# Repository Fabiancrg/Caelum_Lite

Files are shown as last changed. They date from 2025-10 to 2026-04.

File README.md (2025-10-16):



| Supported Targets | ESP32-C6 | ESP32-H2 || Supported Targets | ESP32-C6 | ESP32-H2 |

| ----------------- |  -------- | -------- || ----------------- |  -------- | -------- |

# ESP32 Zigbee Weather Station# ESP32 Zigbee Multi-Sensor Device

This project implements a comprehensive weather monitoring station using ESP32-C6 with Zigbee connectivity. The device is derived from the ZigbeeMultiSensor project and provides real-time environmental monitoring with multiple sensors.This project implements a comprehensive environmental monitoring device using ESP32-C6 with Zigbee connectivity. The device combines multiple sensors and actuators into a single Zigbee end-device with five distinct endpoints.

This project is based on the examples provided in the ESP Zigbee SDK:This project is based on the exmaples provided in the ESP Zigbee SDK :

* [ESP Zigbee SDK Docs](https://docs.espressif.com/projects/esp-zigbee-sdk)* [ESP Zigbee SDK Docs](https://docs.espressif.com/projects/esp-zigbee-sdk)

* [ESP Zigbee SDK Repo](https://github.com/espressif/esp-zigbee-sdk)* [ESP Zigbee SDK Repo](https://github.com/espressif/esp-zigbee-sdk)

## Device Features## Device Features

### 🌐 Zigbee Endpoints Overview### 🌐 Zigbee Endpoints Overview

| Endpoint | Device Type | Clusters | Description || Endpoint | Device Type | Clusters | Description |

|----------|-------------|----------|-------------||----------|-------------|----------|-------------|

| **1** | LED Strip Light | On/Off | Addressable LED strip (GPIO 8) with status indication || **1** | LED Strip Light | On/Off | Addressable LED strip (GPIO 8) with full on/off control |

| **2** | GPIO LED Light | On/Off | Single GPIO LED (GPIO 0) for secondary status || **2** | GPIO LED Light | On/Off | Single GPIO LED (GPIO 0) for secondary lighting |

| **3** | Button Sensor | Analog Input | External button (GPIO 12) with multi-action detection || **3** | Button Sensor | Analog Input | External button (GPIO 12) with multi-action detection |

| **4** | Environmental Sensor | Temperature, Humidity, Pressure | BME280 sensor via I2C (GPIO 6/7) || **4** | Environmental Sensor | Temperature, Humidity, Pressure | BME280 sensor via I2C (GPIO 6/7) |

| **5** | Rain Gauge | Analog Input | Tipping bucket rain sensor (GPIO 18) with rainfall totals || **5** | Rain Gauge | Analog Input | Tipping bucket rain sensor (GPIO 18) with rainfall totals |

### 📋 Weather Monitoring Capabilities### 📋 Detailed Endpoint Descriptions

#### **Temperature Monitoring** 🌡️#### **Endpoint 1: LED Strip Controller** 

- Range: -40°C to +85°C- **Hardware**: WS2812B-compatible LED strip on GPIO 8

- Accuracy: ±1°C- **Functionality**: Full on/off control with Zigbee integration

- Real-time updates via Zigbee reporting- **Features**: Hardware state tracking, button toggle support

- **Use Case**: Primary lighting control and status indication

#### **Humidity Monitoring** 💧

- Range: 0-100% RH#### **Endpoint 2: GPIO LED Controller**

- Accuracy: ±3% RH- **Hardware**: Standard LED on GPIO 0  

- Automatic dew point calculation- **Functionality**: Simple on/off switching

- **Features**: Independent control from LED strip

#### **Barometric Pressure** ☁️- **Use Case**: Secondary status indicator or backup lighting

- Range: 300-1100 hPa

- Weather trend prediction#### **Endpoint 3: Smart Button Interface**

- Altitude compensation- **Hardware**: Push button on GPIO 12

- **Functionality**: Multi-action detection (single, double, hold, release)

#### **Rainfall Measurement** 🌧️- **Features**: Debounced input, action encoding, press counting

- Tipping bucket sensor support- **Use Case**: User interface for device control and interaction

- Cumulative rainfall tracking

- Configurable reset intervals#### **Endpoint 4: Environmental Monitoring**

- **Hardware**: BME280 sensor via I2C (SDA: GPIO 6, SCL: GPIO 7)

### 🔧 Hardware Requirements- **Measurements**: 

  - 🌡️ **Temperature**: -40°C to +85°C (±1°C accuracy)

- **MCU**: ESP32-C6 or ESP32-H2  - 💧 **Humidity**: 0-100% RH (±3% accuracy) 

- **Environmental Sensor**: BME280 (I2C)  - 🌪️ **Pressure**: 300-1100 hPa (±1 hPa accuracy)

  - SDA: GPIO 6- **Features**: Automatic 30-second reporting, Zigbee-standard units

  - SCL: GPIO 7- **Use Case**: Weather monitoring, HVAC automation, air quality tracking

- **Rain Sensor**: Tipping bucket on GPIO 18

- **LED Strip**: WS2812B on GPIO 8 (optional)#### **Endpoint 5: Rain Gauge System**

- **Status LED**: GPIO 0 (optional)- **Hardware**: Tipping bucket rain gauge on GPIO 18

- **Button**: GPIO 12 (optional)- **Measurements**: Cumulative rainfall in millimeters (0.36mm per tip)

- **Features**: 

### 📊 Zigbee Integration  - Advanced debouncing (200ms + 1000ms bounce settle)

  - Persistent storage (NVS) for total tracking

- **Protocol**: Zigbee 3.0  - Smart reporting (1mm threshold OR hourly)

- **Device Type**: End Device (Router mode available)  - Network-aware operation (only active when connected)

- **Supported Channels**: 11-26 (2.4 GHz)- **Specifications**: 

- **Compatible**: Zigbee2MQTT, Home Assistant ZHA, Hubitat  - Maximum rate: 200mm/hour supported

  - Accuracy: ±0.36mm per bucket tip

### 🚀 Getting Started  - Storage: Non-volatile total persistence across reboots

- **Use Case**: Weather station, irrigation control, flood monitoring

#### Prerequisites

```bash### 🔧 Hardware Configuration

# Install ESP-IDF v5.5.1 or later

git clone -b v5.5.1 --recursive https://github.com/espressif/esp-idf.git#### **Required Components**

cd esp-idf- ESP32-C6 development board

./install.sh esp32c6- BME280 environmental sensor module

. ./export.sh- WS2812B LED strip (at least 1 LED)

```- Standard LED + resistor

- Push button + pull-up resistor  

#### Build and Flash- Tipping bucket rain gauge with reed switch

```bash- Zigbee coordinator (ESP32-H2 or commercial gateway)

cd WeatherStation

idf.py set-target esp32c6#### **Pin Assignments**

idf.py build```

idf.py -p COM_PORT flash monitorGPIO 0  - GPIO LED output

```GPIO 6  - I2C SDA (BME280)

GPIO 7  - I2C SCL (BME280) 

#### First BootGPIO 8  - LED strip data (WS2812B)

1. Device will create a Zigbee network or join existing oneGPIO 9  - Built-in button (factory reset)

2. LED indicators show connection statusGPIO 12 - External button input

3. Long-press button (5s) for factory resetGPIO 18 - Rain gauge input (reed switch)

```

### 📡 Data Reporting

## 🚀 Quick Start

- **Temperature/Humidity**: Every 30 seconds or on significant change

- **Pressure**: Every 60 seconds### Configure the Project

- **Rainfall**: Immediate on tip detection```bash

- **Button Events**: Immediate (single, double, hold, release)idf.py set-target esp32c6

idf.py menuconfig

### 🏠 Home Assistant Integration```

The device appears as a Zigbee climate sensor with:### Build and Flash

- Temperature sensor```bash

- Humidity sensor# Erase previous data (recommended for first flash)

- Pressure sensoridf.py -p [PORT] erase-flash

- Rainfall sensor

- LED controls# Build and flash the project

- Button entityidf.py -p [PORT] flash monitor

```

### 🛠️ Configuration

### Device Operation

Key parameters can be adjusted in `main/esp_zb_light.h`:

- Reporting intervals#### **Button Controls**

- Sensor calibration offsets- **Built-in Button (GPIO 9)**:

- Rain tip bucket volume  - Short press: Toggle LED strip on/off

- LED behavior  - Long press (hold): Factory reset device

- **External Button (GPIO 12)**: 

### 📝 Project Structure  - Reports all actions (single, double, hold, release) to Zigbee

```#### **Automatic Features**

WeatherStation/- Environmental data reported every 30 seconds

├── main/- Rain gauge totals stored persistently  

│   ├── esp_zb_light.c       # Main Zigbee stack logic- Smart rainfall reporting (1mm increments or hourly)

│   ├── esp_zb_light.h       # Configuration and headers- Network connection status monitoring

│   ├── bme280_app.c         # BME280 sensor driver

│   ├── bme280_app.h         # BME280 interface## 📊 Example Output

│   ├── light_driver.c       # LED strip and GPIO control

│   └── light_driver.h       # Light driver interface### Device Initialization

├── CMakeLists.txt           # Build configuration```

├── sdkconfig.defaults       # Default SDK settingsI (403) app_start: Starting scheduler on CPU0

└── README.md                # This fileI (408) ESP_ZB_ON_OFF_LIGHT: Initialize Zigbee stack

```I (558) ESP_ZB_ON_OFF_LIGHT: Deferred driver initialization successful

I (568) ESP_ZB_ON_OFF_LIGHT: BME280 sensor initialized successfully

### 🔄 Based OnI (578) ESP_ZB_ON_OFF_LIGHT: Rain gauge initialized successfully. Current total: 0.00 mm

I (578) ESP_ZB_ON_OFF_LIGHT: Start network steering

This project is derived from the ESP32 Zigbee Multi-Sensor Device project and inherits its multi-endpoint architecture optimized for weather station applications.```

### 📄 License### Network Connection

```

This project follows the license terms of the ESP Zigbee SDK.I (3558) ESP_ZB_ON_OFF_LIGHT: Joined network successfully (Extended PAN ID: 74:4d:bd:ff:fe:63:f7:30, PAN ID: 0x13af, Channel:13, Short Address: 0x7c16)

I (3568) RAIN_GAUGE: Rain gauge enabled - device connected to Zigbee network

### 🤝 Contributing```

Contributions are welcome! Please feel free to submit issues or pull requests.### Sensor Data Reporting

```

### 💖 SupportI (30000) ESP_ZB_ON_OFF_LIGHT: 🌡️ Temperature: 22.35°C reported to Zigbee  

I (30010) ESP_ZB_ON_OFF_LIGHT: 💧 Humidity: 45.20% reported to Zigbee

If you find this project useful, consider supporting the development:I (30020) ESP_ZB_ON_OFF_LIGHT: 🌪️ Pressure: 1013.25 hPa reported to Zigbee

I (30030) ESP_ZB_ON_OFF_LIGHT: 📡 Temp: 22.4°C

[![ko-fi](https://ko-fi.com/img/githubbutton_sm.svg)](https://ko-fi.com/Fabiancrg)I (30040) ESP_ZB_ON_OFF_LIGHT: 📡 Humidity: 45.2%

I (30050) ESP_ZB_ON_OFF_LIGHT: 📡 Pressure: 1013.3 hPa
```

### Button Interactions  
```
I (45000) ESP_ZB_ON_OFF_LIGHT: 🔘 External button action detected: single
I (45010) ESP_ZB_ON_OFF_LIGHT: ✅ Button action single sent (encoded: 1001.0) - press #1
I (45020) ESP_ZB_ON_OFF_LIGHT: 📡 Button: single (#1)
```

### Rain Gauge Activity
```  
I (60000) RAIN_GAUGE: 🔍 Rain gauge interrupt received on GPIO18 (enabled: YES)
I (60010) RAIN_GAUGE: 🌧️ Rain pulse #1 detected! Total: 0.36 mm (+0.36 mm)
I (60020) RAIN_GAUGE: ✅ Rainfall total 0.36 mm reported to Zigbee
I (60030) ESP_ZB_ON_OFF_LIGHT: 📡 Rain: 0.36 mm
```

## 🏠 Home Assistant Integration

When connected to Zigbee2MQTT or other Zigbee coordinators, the device appears as:

- **2x Switch entities**: LED Strip & GPIO LED control
- **1x Sensor entity**: Button actions with press counter
- **3x Sensor entities**: Temperature, Humidity, Pressure  
- **1x Sensor entity**: Rainfall total with automatic updates

### Device Information
- **Manufacturer**: ESPRESSIF
- **Model**: esp32c6  
- **Firmware**: v5.5.1
- **Supported**: Automatic device detection in Zigbee2MQTT

## 🔧 Troubleshooting

### Common Issues

#### **Rain Gauge Not Detecting**
- Verify GPIO 18 connections and reed switch operation
- Check that device is connected to Zigbee network (rain gauge only active when connected)
- Ensure proper pull-down resistor on rain gauge input

#### **BME280 Not Reading**  
- Check I2C connections (SDA: GPIO 6, SCL: GPIO 7)
- Verify BME280 I2C address (default: 0x76 or 0x77)
- Ensure proper power supply to sensor (3.3V)

#### **Button Not Responding**
- Verify button connections and pull-up resistors
- Check GPIO 12 (external) and GPIO 9 (built-in) functionality
- Ensure proper debouncing in hardware

#### **Zigbee Connection Issues**
- Perform factory reset with long press on built-in button
- Ensure Zigbee coordinator is in pairing mode
- Check channel compatibility between coordinator and device

### 📋 Development Notes

- **ESP-IDF Version**: v5.5.1 recommended
- **Zigbee SDK**: Latest ESP Zigbee SDK required  
- **Memory Usage**: ~2MB flash, ~200KB RAM typical
- **Power Consumption**: ~100mA active, supports deep sleep for battery operation

### 🆘 Support

For technical queries, please open an [issue](https://github.com/espressif/esp-idf/issues) on GitHub. Include:
- Complete serial monitor output
- Hardware configuration details  
- ESP-IDF and SDK versions
- Specific symptoms and reproduction steps

---

**Project**: ESP32 Zigbee Multi-Sensor Device  
**Version**: v1.0  
**Compatible**: ESP32-C6, ESP-IDF v5.5.1+  
**License**: Apache 2.0

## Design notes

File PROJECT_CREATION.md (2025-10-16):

# WeatherStation Project Creation Summary

## Overview
Successfully created a new **WeatherStation** project based on the **ZigbeeMultiSensor** project.

## Project Location
```
c:\Devel\Repositories\WeatherStation
```

## What Was Done

### 1. Project Structure Copied
All essential files and directories were copied from ZigbeeMultiSensor:
- ✅ Source code (`main/` directory with all .c and .h files)
- ✅ Build configuration (`CMakeLists.txt`, `sdkconfig`, `sdkconfig.defaults`)
- ✅ Development tools (`.vscode/`, `.devcontainer/`, `.clangd`)
- ✅ Project metadata (`.gitignore`, `partitions.csv`)

### 2. Excluded Items (Clean Copy)
The following were intentionally excluded:
- ❌ `.git/` - No git history (fresh start)
- ❌ `build/` - Build artifacts (will be regenerated)
- ❌ `managed_components/` - Will be downloaded on first build
- ❌ `dependencies.lock` - Will be regenerated
- ❌ Build logs and temporary files

### 3. Project Renamed
- **CMakeLists.txt**: Project name changed from `zigbeeTest` to `WeatherStation`
- **README.md**: Completely rewritten for weather station focus

## Project Features (Inherited from ZigbeeMultiSensor)

### Hardware Support
- **MCU**: ESP32-C6 or ESP32-H2
- **Zigbee**: Full Zigbee 3.0 stack with 5 endpoints

### Endpoints Configuration
1. **Endpoint 1**: LED Strip (WS2812B on GPIO 8)
2. **Endpoint 2**: GPIO LED (GPIO 0)
3. **Endpoint 3**: Button Sensor (GPIO 12)
4. **Endpoint 4**: BME280 Environmental Sensor (I2C on GPIO 6/7)
5. **Endpoint 5**: Rain Gauge (GPIO 18)

### Source Files Included
```
main/
├── bme280_app.c         # BME280 sensor driver
├── bme280_app.h         # BME280 interface
├── esp_zb_light.c       # Main Zigbee stack (49KB)
├── esp_zb_light.h       # Configuration headers
├── light_driver.c       # LED/GPIO control (19KB)
├── light_driver.h       # Driver interface
├── CMakeLists.txt       # Component config
└── idf_component.yml    # Dependencies
```

## Next Steps

### 1. Initialize Git (Optional)
```bash
cd c:\Devel\Repositories\WeatherStation
git init
git add .
git commit -m "Initial commit - Weather Station project based on ZigbeeMultiSensor"
```

### 2. Build the Project
```bash
cd c:\Devel\Repositories\WeatherStation

# Set target (if not already set)
idf.py set-target esp32c6

# Build
idf.py build
```

### 3. Flash to Device
```bash
# Erase flash (recommended for first flash)
idf.py erase-flash

# Flash and monitor
idf.py -p COM_PORT flash monitor
```

### 4. Customization Ideas
Consider modifying for weather station specific features:
- Add weather trend calculation (pressure changes)
- Implement data logging to flash
- Add wind speed/direction sensors
- Customize LED patterns for weather alerts
- Add battery monitoring for solar power

## Configuration Files

### Key Settings in `sdkconfig`
- Zigbee role: End Device (can be changed to Router)
- I2C configuration for BME280
- GPIO assignments for sensors and LEDs

### Component Dependencies (`main/idf_component.yml`)
- LED strip driver
- BME280 sensor library
- ESP-Zigbee libraries

## Differences from Original

| Aspect | ZigbeeMultiSensor | WeatherStation |
|---|---|---|
| Project Name | `zigbeeTest` | `WeatherStation` |
| README | Multi-sensor focus | Weather station focus |
| Git History | Preserved | Fresh start (no .git) |
| Build Artifacts | May exist | Clean (excluded) |

## Testing Checklist

Before first use, verify:
- [ ] ESP-IDF environment is set up (v5.5.1+)
- [ ] ESP32-C6 or ESP32-H2 hardware available
- [ ] BME280 sensor connected to I2C (GPIO 6/7)
- [ ] USB cable and COM port identified
- [ ] Zigbee coordinator running (Zigbee2MQTT or ZHA)

## Support

This project inherits all features from ZigbeeMultiSensor and is optimized for weather monitoring applications.

For issues or contributions, refer to the main README.md in the project directory.

---
**Created**: October 16, 2025
**Based on**: ZigbeeMultiSensor by Fabiancrg
**Status**: Ready to build and flash

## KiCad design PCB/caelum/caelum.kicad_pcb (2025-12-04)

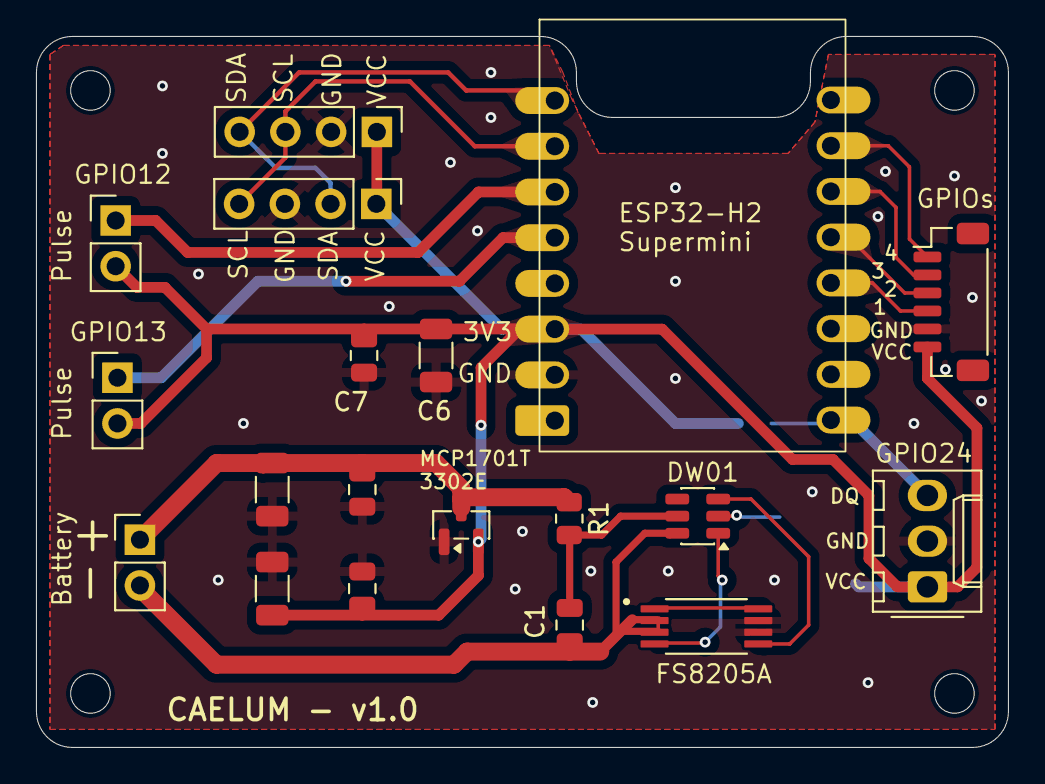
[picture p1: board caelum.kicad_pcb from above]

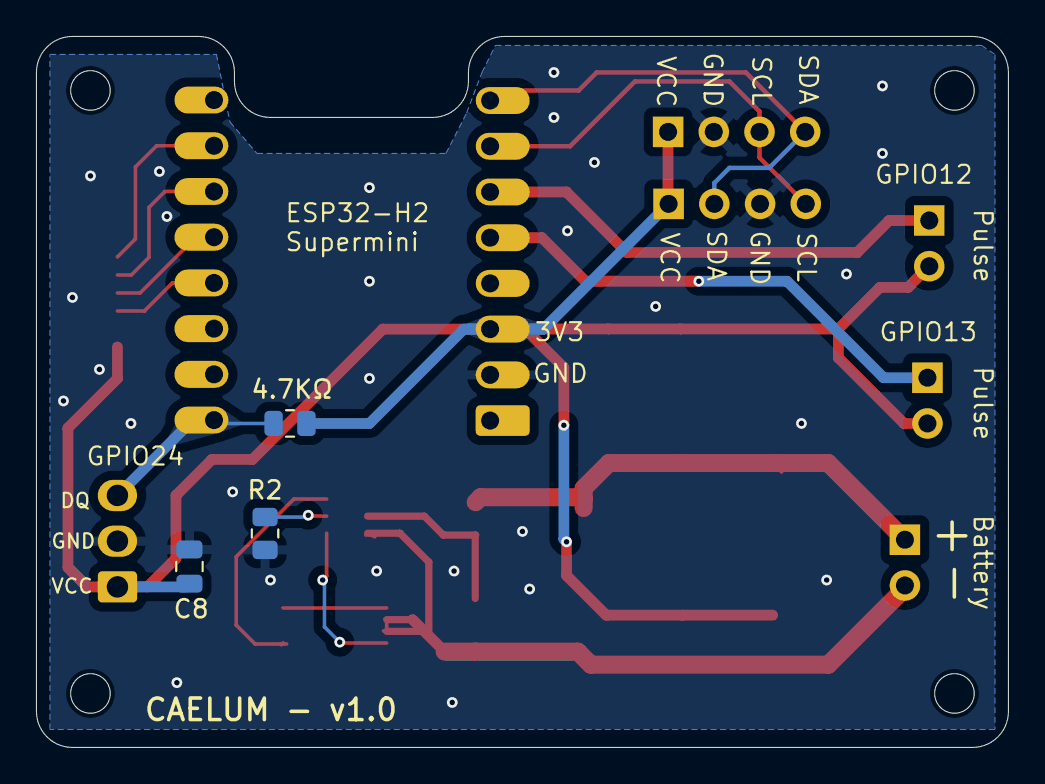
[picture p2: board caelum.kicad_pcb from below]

Board: 2 copper layers, 54.0 x 39.5 mm, 26 parts (3 on the bottom side), 18 nets.

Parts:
C1, C3, C5, C7, C8: 0.1µF; C_0805_2012Metric
C2, C4, C6: 1µF; C_1206_3216Metric
H1, H2, H3, H4: MountingHole; MountingHole_2.2mm_M2
J1: Conn_01x06_Pin; JST_SH_BM06B-SRSS-TB_1x06-1MP_P1.00mm_Vertical
J3: Pulse1; PinHeader_1x02_P2.54mm_Vertical
J4: Batt; PinHeader_1x02_P2.54mm_Vertical
J6: Pulse2; PinHeader_1x02_P2.54mm_Vertical
J7, J10: Conn_01x04_Pin; PinHeader_1x04_P2.54mm_Vertical
J8: DS18B20; Molex_KK-254_AE-6410-03A_1x03_P2.54mm_Vertical
Q1: FS8205A-FC; SOP65P640X120-8N-FC
R1: 100R; R_0805_2012Metric
R2: 1K; R_0805_2012Metric
R3: 4.7K; R_0805_2012Metric
U1: DW01A; SOT-23-6
U2: MCP1700T-3302E; SOT-23
U3: ESP32-H2-SUPERMINI; ESP32H2-Supermini

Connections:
+3V3: C4.2, C5.2, C6.1, C7.1, C8.2, J1.6, J3.2, J6.2, J7.1, J8.1, J10.1, R3.1, U2.2 (VO), U3.7 (3V3)
BATT+: C2.1, C3.1, J4.1, R1.1, U2.3 (VI)
BATT-: C1.2, J4.2, Q1.2 (S1), Q1.3 (S1), U1.6 (GND)
GPIO1: J1.4, U3.16 (IO1)
GPIO2: J1.3, U3.15 (IO2)
GPIO3: J1.2, U3.14 (IO3)
GPIO4: J1.1, U3.13 (IO4)
GPIO12: J3.1, U3.4 (IO12)
GPIO13: J6.1, U3.5 (IO13)
GPIO24: J8.3, R3.2, U3.19 (IO24)
unnamed: Q1.1 (D12), Q1.8 (D12)
unnamed: Q1.4 (G1), U1.1 (OD)
unnamed: Q1.5 (G2), U1.3 (OC)
unnamed: R2.1, U1.2 (CS)
unnamed: C1.1, R1.2, U1.5 (VCC)
OUT-: C2.2, C3.2, C4.1, C5.1, C6.2, C7.2, C8.1, J1.5, J7.3, J8.2, J10.2, Q1.6 (S2), Q1.7 (S2), R2.2, U2.1 (GND), U3.8 (GND)
SCL: J7.4, J10.3, U3.3 (IO11)
SDA: J7.2, J10.4, U3.2 (IO10)

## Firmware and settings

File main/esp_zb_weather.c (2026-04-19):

/*
 * SPDX-FileCopyrightText: 2021-2024 Espressif Systems (Shanghai) CO LTD
 *
 * SPDX-License-Identifier:  LicenseRef-Included
 *
 * ESP32-H2 Zigbee Weather Station with Light Sleep
 *
 * Battery-powered weather station with 5-minute periodic sensor readings.
 * Rain gauge triggers immediate attribute updates on each pulse.
 * Uses light sleep to maintain Zigbee network connection.
 * All reporting controlled by Zigbee coordinator configuration.
 */
#include "freertos/FreeRTOS.h"
#include "freertos/task.h"
#include "freertos/queue.h"
#include "freertos/semphr.h"
#include "esp_check.h"
#include "esp_log.h"
#include "nvs_flash.h"
#include "ha/esp_zigbee_ha_standard.h"
#include "esp_zb_weather.h"
#include "esp_zb_ota.h"
#include "sleep_manager.h"
#include "driver/gpio.h"
#include "bme280_app.h"
#include "sensor_if.h"
#include "i2c_bus.h"
#include "nvs.h"
#include "weather_driver.h"
#include "esp_adc/adc_oneshot.h"
#include "esp_adc/adc_cali.h"
#include "esp_adc/adc_cali_scheme.h"
#include "esp_ota_ops.h"
#include "esp_app_format.h"
#include "esp_timer.h"
#include "esp_pm.h"
#include "esp_sleep.h"
#include "esp_rom_uart.h"
#include "driver/rmt_tx.h"
#include "driver/rmt_rx.h"
/* Generated header with FW_VERSION / FW_DATE_CODE - created at configure time */
#include "version.h"

/* OTA upgrade running versions */
#ifndef OTA_UPGRADE_RUNNING_FILE_VERSION
#define OTA_UPGRADE_RUNNING_FILE_VERSION                      0x00000000U
#endif
#ifndef OTA_UPGRADE_RUNNING_STACK_VERSION
#define OTA_UPGRADE_RUNNING_STACK_VERSION                     0x0002U
#endif

#if !defined ZB_ED_ROLE
#error Define ZB_ED_ROLE in idf.py menuconfig to compile Weather Station (End Device) source code.
#endif

/* Zigbee Sleepy End Device (SED) configuration */
#define ZIGBEE_KEEP_ALIVE_MS        7500    // Keep-alive poll interval (7.5 seconds)
#define ZIGBEE_SLEEP_THRESHOLD_MS   6000    // Idle time before sleep signal (6 seconds)
#define ZIGBEE_ED_TIMEOUT           ESP_ZB_ED_AGING_TIMEOUT_64MIN  // Parent timeout

/* Power optimization notes:
 * - Sleep threshold MUST be < keep_alive to allow CAN_SLEEP signal before next poll
 * - Lower threshold = faster sleep entry = better battery life
 * - Higher threshold = more time for multiple reports = fewer wake cycles
 * - Current setting (6s): Optimal for 15-min reporting with occasional rain events
 * - Measured performance: 0.68mA sleep, 12mA transmit, ~0.83mA average
 * - Battery life: ~125 days (4 months) on 2500mAh Li-Ion
 */

static const char *TAG = "WEATHER_STATION";
//static const char *RAIN_TAG = "RAIN_GAUGE";

/* Network connection status - declared early for LED functions */
static bool zigbee_network_connected = false;

/* Sleep prevention during initial configuration
 * Prevents device from sleeping for 60 seconds after joining network
 * This gives coordinator (Z2M) time to configure reporting without interruption.
 * IMPORTANT: We use a PM lock instead of skipping esp_zb_sleep_now() — the Zigbee
 * stack requires that esp_zb_sleep_now() is ALWAYS called on CAN_SLEEP, otherwise
 * the internal critical section nesting becomes unbalanced and causes a crash. */
static int64_t network_join_time_us = 0;
static esp_pm_lock_handle_t config_pm_lock = NULL;
#define INITIAL_CONFIG_DELAY_SEC 60  // Wait 60 seconds before allowing sleep after join

/* LED is used only during boot/join process:
 * - Blink yellow/orange during network joining
 * - Steady blue when successfully connected
 * - Blink red after max connection retries failed
 * After successful join, LED strip is deinitialized to save power */

#include "led_strip.h"

/* Debug LED variables for RGB LED */
static led_strip_handle_t led_strip = NULL;
static bool led_blink_task_running = false;
static TaskHandle_t led_blink_task_handle = NULL;

/* LED control functions for WS2812 RGB LED */
static void debug_led_init(void)
{
    /* LED strip configuration for WS2812 (older API for led_strip ~2.0.0) */
    led_strip_config_t strip_config = {
        .strip_gpio_num = DEBUG_LED_GPIO,
        .max_leds = 1,                         // Only 1 LED
    };
    
    /* LED strip RMT configuration (older API) */
    led_strip_rmt_config_t rmt_config = {
        .resolution_hz = 10 * 1000 * 1000,     // 10MHz
    };
    
    ESP_ERROR_CHECK(led_strip_new_rmt_device(&strip_config, &rmt_config, &led_strip));
    
    /* Turn off LED initially */
    led_strip_clear(led_strip);
    ESP_LOGI(TAG, "Debug RGB LED initialized on GPIO%d (WS2812)", DEBUG_LED_GPIO);
}

static void debug_led_deinit(void)
{
    /* Deinitialize LED strip to power down RMT peripheral
     * Called after successful network join to save power */
    if (led_strip) {
        led_strip_clear(led_strip);  // Clear pixels first
        led_strip_del(led_strip);    // Delete LED strip handle (powers down RMT)
        led_strip = NULL;
        ESP_LOGI(TAG, "🔌 RGB LED RMT peripheral powered down (boot sequence complete)");
    }
}

/* Properly-typed wrapper for esp_zb_scheduler_alarm (avoids UB from void(void)->void(uint8_t) cast) */
static void debug_led_deinit_cb(uint8_t param)
{
    (void)param;
    debug_led_deinit();
}

static void debug_led_set_blue(void)
{
    /* Set steady blue for successful connection */
    if (led_strip) {
        led_strip_set_pixel(led_strip, 0, 0, 0, 16);  // R=0, G=0, B=16 (dim blue)
        led_strip_refresh(led_strip);
    }
}

static void debug_led_blink_task(void *arg)
{
    while (led_blink_task_running) {
        if (!led_strip) break;  // Stop if LED was deinitialized
        
        /* Yellow/orange blink for network joining */
        led_strip_set_pixel(led_strip, 0, 16, 8, 0);  // R=16, G=8, B=0 (dim yellow/orange)
        led_strip_refresh(led_strip);
        vTaskDelay(pdMS_TO_TICKS(500));  // ON for 500ms
        
        led_strip_set_pixel(led_strip, 0, 0, 0, 0);   // OFF
        led_strip_refresh(led_strip);
        vTaskDelay(pdMS_TO_TICKS(500));  // OFF for 500ms
    }
    vTaskDelete(NULL);
}

static void debug_led_start_blink(void)
{
    if (!led_strip) return;  // LED already deinitialized
    
    if (!led_blink_task_running) {
        led_blink_task_running = true;
        xTaskCreate(debug_led_blink_task, "led_blink", 2048, NULL, 5, &led_blink_task_handle);
        ESP_LOGI(TAG, "RGB LED blink started (network joining)");
    }
}

static void debug_led_stop_blink(void)
{
    if (led_blink_task_running) {
        led_blink_task_running = false;
        if (led_blink_task_handle) {
            vTaskDelay(pdMS_TO_TICKS(10));  // Give task time to exit
            led_blink_task_handle = NULL;
        }
    }
}

static void debug_led_blink_red(void)
{
    /* Blink red to indicate connection failure after max retries */
    if (!led_strip) return;
    
    for (int i = 0; i < 10; i++) {  // Blink 10 times
        led_strip_set_pixel(led_strip, 0, 16, 0, 0);  // R=16, G=0, B=0 (dim red)
        led_strip_refresh(led_strip);
        vTaskDelay(pdMS_TO_TICKS(200));  // ON for 200ms
        
        led_strip_set_pixel(led_strip, 0, 0, 0, 0);   // OFF
        led_strip_refresh(led_strip);
        vTaskDelay(pdMS_TO_TICKS(200));  // OFF for 200ms
    }
}

/* Rain gauge configuration */
#define RAIN_GAUGE_GPIO         12              // GPIO pin for rain gauge reed switch
#define RAIN_MM_PER_PULSE       0.36f           // mm of rain per bucket tip (adjust for your sensor)

typedef enum {
    RAIN_EVENT_PULSE = 0,
    RAIN_EVENT_FLUSH,
} rain_event_type_t;

/* Rain gauge queue event */
typedef struct {
    rain_event_type_t type;
    TickType_t tick;
    bool force_nvs;
    bool force_attribute;
} rain_evt_t;

/* Pulse counter configuration (GPIO13) */
#define PULSE_COUNTER_GPIO      13              // GPIO pin for pulse counter input
#define PULSE_COUNTER_VALUE     1.0f            // Value per pulse (can be adjusted)

typedef enum {
    PULSE_EVENT_PULSE = 0,
    PULSE_EVENT_FLUSH,
} pulse_event_type_t;

/* Pulse counter queue event */
typedef struct {
    pulse_event_type_t type;
    TickType_t tick;
    bool force_nvs;
    bool force_attribute;
} pulse_evt_t;

static QueueHandle_t rain_gauge_evt_queue = NULL;
static float total_rainfall_mm = 0.0f;
static uint32_t rain_pulse_count = 0;
static const char *RAIN_TAG = "RAIN_GAUGE";
static bool rain_gauge_enabled = false;  // Only enable when connected to network
static bool rain_gauge_isr_installed = false;  // Track ISR installation state
static esp_timer_handle_t rain_flush_timer = NULL;

/* Pulse counter variables (GPIO13) */
static QueueHandle_t pulse_counter_evt_queue = NULL;
static float total_pulse_count_value = 0.0f;
static uint32_t pulse_counter_count = 0;
static const char *PULSE_TAG = "PULSE_COUNTER";
static bool pulse_counter_enabled = false;  // Only enable when connected to network
static bool pulse_counter_isr_installed = false;  // Track ISR installation state
static esp_timer_handle_t pulse_flush_timer = NULL;

/* DS18B20 temperature sensor (GPIO24) */
static const char *DS18B20_TAG = "DS18B20";
static float ds18b20_last_temp = 0.0f;
static bool ds18b20_available = false;

/* Periodic sensor reading interval (5 minutes as per requirements) */
#define PERIODIC_READING_INTERVAL_MS (5 * 60 * 1000ULL)  // 5 minutes in milliseconds
#define RAIN_PULSE_FLUSH_THRESHOLD   10U
#define RAIN_FLUSH_INTERVAL_US       (10ULL * 1000ULL * 1000ULL) // 10 seconds
static esp_timer_handle_t periodic_report_timer = NULL;

/* Heartbeat logging for debugging - logs every 30 minutes to prove device is alive */
#define HEARTBEAT_INTERVAL_MS (30 * 60 * 1000ULL)  // 30 minutes
static esp_timer_handle_t heartbeat_timer = NULL;

/* Sensor reading task - runs in separate task to avoid blocking Zigbee scheduler */
static QueueHandle_t sensor_read_queue = NULL;
static TaskHandle_t sensor_read_task_handle = NULL;

/* Network connection status (zigbee_network_connected declared earlier for LED functions) */
static uint32_t connection_retry_count = 0;
#define NETWORK_RETRY_SLEEP_DURATION    30      // 30 seconds for network retry
#define MAX_CONNECTION_RETRIES          20      // Max fast retries before switching to backoff

/* Exponential backoff for reconnection after max fast retries exhausted */
static uint32_t backoff_attempt = 0;
#define BACKOFF_INITIAL_MS              (30  * 1000)    // 30 seconds
#define BACKOFF_MAX_MS                  (600 * 1000)    // 10 minutes cap

static uint32_t get_backoff_delay_ms(void)
{
    /* Exponential backoff: 30s, 60s, 120s, 240s, 480s, capped at 600s */
    uint32_t delay = BACKOFF_INITIAL_MS << backoff_attempt;  // 30s * 2^attempt
    if (delay > BACKOFF_MAX_MS || delay < BACKOFF_INITIAL_MS) {  // overflow guard
        delay = BACKOFF_MAX_MS;
    }
    if (backoff_attempt < 10) {  // prevent shift overflow
        backoff_attempt++;
    }
    return delay;
}

/* Ensure shared GPIO ISR service exists before adding any handler.
 * This avoids boot-time failures when a deferred init path partially fails.
 */
static bool ensure_gpio_isr_service_installed(const char *subsystem_tag, const char *subsystem_name)
{
    esp_err_t isr_ret = gpio_install_isr_service(ESP_INTR_FLAG_DEFAULT);
    if (isr_ret == ESP_OK || isr_ret == ESP_ERR_INVALID_STATE) {
        return true;
    }

    ESP_LOGE(subsystem_tag, "Failed to install GPIO ISR service for %s: %s",
             subsystem_name, esp_err_to_name(isr_ret));
    return false;
}

/* Button action tracking (no state needed for action-based buttons) */
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
void app_main(void)
{
    /* Initialize NVS */
    ESP_ERROR_CHECK(nvs_flash_init());
    
    /* Initialize debug LED */
    debug_led_init();
    
    /* Initialize OTA */
    ESP_ERROR_CHECK(esp_zb_ota_init());

    /* Create PM lock for initial config period (prevents sleep after network join) */
    if (esp_pm_lock_create(ESP_PM_NO_LIGHT_SLEEP, 0, "config_no_sleep", &config_pm_lock) != ESP_OK) {
        ESP_LOGW(TAG, "Failed to create config PM lock");
        config_pm_lock = NULL;
    }
    
    /* Initialize power management for light sleep */
    ESP_ERROR_CHECK(esp_zb_power_save_init());
    
    /* Enable GPIO wakeup globally for light sleep */
    esp_err_t gpio_wake_ret = esp_sleep_enable_gpio_wakeup();
    if (gpio_wake_ret == ESP_OK) {
        ESP_LOGI(TAG, "✅ GPIO wakeup enabled for light sleep");
    } else {
        ESP_LOGW(TAG, "⚠️ Failed to enable GPIO wakeup: %s", esp_err_to_name(gpio_wake_ret));
    }
    
    /* Check wake-up reason and print statistics */
    wake_reason_t wake_reason = check_wake_reason();
    print_wake_statistics();
    
    /* Print battery life estimate (assuming 2500mAh battery) */
    estimate_battery_life(2500);
    
    /* Configure ESP-IDF platform */
    esp_zb_platform_config_t config = {
        .radio_config = ESP_ZB_DEFAULT_RADIO_CONFIG(),
        .host_config = ESP_ZB_DEFAULT_HOST_CONFIG(),
    };
    ESP_ERROR_CHECK(esp_zb_platform_config(&config));
    
    /* Start Zigbee task */
    ESP_LOGI(TAG, "🚀 Starting Caelum Weather Station (Battery Mode)");
    
    /* Log firmware version from app description */
    esp_app_desc_t app_desc_main;
    const esp_partition_t *running = esp_ota_get_running_partition();
    if (esp_ota_get_partition_description(running, &app_desc_main) == ESP_OK) {
        ESP_LOGI(TAG, "📦 Firmware: %s (Date: %s %s)", app_desc_main.version, app_desc_main.date, app_desc_main.time);
    }
    
    #ifdef OTA_FILE_VERSION
        ESP_LOGI(TAG, "⚙️  OTA: Version=0x%08lX, Manufacturer=0x%04X, ImageType=0x%04X", 
                (unsigned long)OTA_FILE_VERSION, OTA_UPGRADE_MANUFACTURER, OTA_UPGRADE_IMAGE_TYPE);
    #else
        ESP_LOGI(TAG, "⚙️  OTA: Manufacturer=0x%04X, ImageType=0x%04X", OTA_UPGRADE_MANUFACTURER, OTA_UPGRADE_IMAGE_TYPE);
    #endif

    ESP_LOGI(TAG, "Wake reason: %s", 
             wake_reason == WAKE_REASON_TIMER ? "TIMER" :
             wake_reason == WAKE_REASON_RAIN ? "RAIN" :
             wake_reason == WAKE_REASON_BUTTON ? "BUTTON" : "RESET");
    
    /* Log network connection status */
    if (zigbee_network_connected) {
        ESP_LOGI(TAG, "📡 Network: Connected");
    } else {
        ESP_LOGW(TAG, "📡 Network: Disconnected (retries: %d/%d)", connection_retry_count, MAX_CONNECTION_RETRIES);
    }
    
    /* Create sensor reading task and queue */
    sensor_read_queue = xQueueCreate(5, sizeof(uint8_t));
    if (sensor_read_queue == NULL) {
        ESP_LOGE(TAG, "Failed to create sensor read queue");
    } else {
        xTaskCreate(sensor_read_task, "sensor_read", 4096, NULL, 4, &sensor_read_task_handle);
        ESP_LOGI(TAG, "✅ Sensor read task created");
    }
    
    xTaskCreate(esp_zb_task, "Zigbee_main", 4096, NULL, 5, NULL);
}

/* Pulse counter implementation (GPIO13) - identical to rain gauge but for general pulse counting */

static void IRAM_ATTR pulse_counter_isr_handler(void *arg)
{
    BaseType_t xHigherPriorityTaskWoken = pdFALSE;

    // ISR-safe: just increment a counter for debugging
    static uint32_t isr_trigger_count = 0;
    isr_trigger_count++;

    /* Prepare event with ISR tick for accurate timing */
    pulse_evt_t evt = {
        .type = PULSE_EVENT_PULSE,
        .tick = xTaskGetTickCountFromISR(),
        .force_nvs = false,
        .force_attribute = false,
    };
    
    /* Only queue event if there's space - prevents overflow from rapid pulses */
    if (xQueueSendFromISR(pulse_counter_evt_queue, &evt, &xHigherPriorityTaskWoken) != pdPASS) {
        /* Queue full - pulse will be lost but prevents crash */
        static uint32_t queue_overflow_count = 0;
        queue_overflow_count++;
    }
    
    if (xHigherPriorityTaskWoken) {
        portYIELD_FROM_ISR();
    }
}

static void pulse_counter_task(void *arg)
{
    pulse_evt_t evt;
    TickType_t last_pulse_time = 0;
    uint32_t pending_pulse_count = 0;
    bool pending_nvs_flush = false;
    bool pending_attr_flush = false;
    const TickType_t DEBOUNCE_TIME = pdMS_TO_TICKS(200); // 200ms debounce

    ESP_LOGI(PULSE_TAG, "Pulse counter task started, waiting for events...");

    for (;;) {
        // Use 10 second timeout instead of portMAX_DELAY to allow watchdog and health checks
        if (xQueueReceive(pulse_counter_evt_queue, &evt, pdMS_TO_TICKS(10000))) {
            switch (evt.type) {
            case PULSE_EVENT_PULSE: {
                TickType_t current_time = evt.tick;

                if ((current_time - last_pulse_time) > DEBOUNCE_TIME) {
                    last_pulse_time = current_time;
                    pending_pulse_count++;
                    pulse_counter_count++;
                    total_pulse_count_value += PULSE_COUNTER_VALUE;
                    total_pulse_count_value = roundf(total_pulse_count_value * 100.0f) / 100.0f;

                    ESP_LOGI(PULSE_TAG, "⚡ Pulse #%u: %.2f total (+%.2f)",
                             pulse_counter_count, total_pulse_count_value, PULSE_COUNTER_VALUE);
                    
                    pending_nvs_flush = true;
                    if (pulse_counter_enabled && zigbee_network_connected) {
                        pending_attr_flush = true;
                    }

                    if (pending_pulse_count >= RAIN_PULSE_FLUSH_THRESHOLD) {
                        ESP_LOGD(PULSE_TAG, "Pulse threshold reached (%u) - flushing totals", pending_pulse_count);
                        pulse_counter_flush_totals(pending_nvs_flush, pending_attr_flush);
                        pending_pulse_count = 0;
                        pending_nvs_flush = false;
                        pending_attr_flush = false;
                        if (pulse_flush_timer != NULL) {
                            esp_timer_stop(pulse_flush_timer);
                        }
                    } else {
                        if (pulse_flush_timer != NULL) {
                            esp_timer_stop(pulse_flush_timer);
                            esp_timer_start_once(pulse_flush_timer, RAIN_FLUSH_INTERVAL_US);
                        }
                    }
                } else {
                    ESP_LOGD(PULSE_TAG, "Pulse ignored - debounce active (%u ms)",
                             pdTICKS_TO_MS(current_time - last_pulse_time));
                }
                break;
            }

            case PULSE_EVENT_FLUSH: {
                bool do_nvs = pending_nvs_flush || evt.force_nvs;
                bool do_attr = pending_attr_flush || evt.force_attribute;

                if (do_nvs || do_attr) {
                    pulse_counter_flush_totals(do_nvs, do_attr);
                    pending_pulse_count = 0;
                    pending_nvs_flush = false;
                    pending_attr_flush = false;
                }
                if (pulse_flush_timer != NULL) {
                    esp_timer_stop(pulse_flush_timer);
                }
                break;
            }

            default:
                break;
            }
        }
    }
}

static void pulse_flush_timer_callback(void *arg)
{
    pulse_counter_request_flush(false, false);
}

static void pulse_counter_request_flush(bool force_nvs, bool force_attribute)
{
    if (pulse_counter_evt_queue == NULL) {
        return;
    }

    pulse_evt_t evt = {
        .type = PULSE_EVENT_FLUSH,
        .tick = xTaskGetTickCount(),
        .force_nvs = force_nvs,
        .force_attribute = force_attribute,
    };

    if (xQueueSend(pulse_counter_evt_queue, &evt, 0) != pdPASS) {
        ESP_LOGW(PULSE_TAG, "Failed to queue pulse flush event (queue full)");
    }
}
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

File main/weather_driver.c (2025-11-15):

/*
 * SPDX-FileCopyrightText: 2021-2023 Espressif Systems (Shanghai) CO LTD
 *
 * SPDX-License-Identifier: LicenseRef-Included
 *
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
 * 3. Neither the name of the copyright holder nor the names of its contributors
 *    may be used to endorse or promote products derived from this software without
 *    specific prior written permission.
 *
 * 4. Any software provided in binary form under this license must not be reverse
 *    engineered, decompiled, modified and/or disassembled.
 *
 * THIS SOFTWARE IS PROVIDED BY THE COPYRIGHT HOLDERS AND CONTRIBUTORS "AS IS"
 * AND ANY EXPRESS OR IMPLIED WARRANTIES, INCLUDING, BUT NOT LIMITED TO, THE
 * IMPLIED WARRANTIES OF MERCHANTABILITY AND FITNESS FOR A PARTICULAR PURPOSE
 * ARE DISCLAIMED. IN NO EVENT SHALL THE COPYRIGHT HOLDER OR CONTRIBUTORS BE
 * LIABLE FOR ANY DIRECT, INDIRECT, INCIDENTAL, SPECIAL, EXEMPLARY, OR
 * CONSEQUENTIAL DAMAGES (INCLUDING, BUT NOT LIMITED TO, PROCUREMENT OF
 * SUBSTITUTE GOODS OR SERVICES; LOSS OF USE, DATA, OR PROFITS; OR BUSINESS
 * INTERRUPTION) HOWEVER CAUSED AND ON ANY THEORY OF LIABILITY, WHETHER IN
 * CONTRACT, STRICT LIABILITY, OR TORT (INCLUDING NEGLIGENCE OR OTHERWISE)
 * ARISING IN ANY WAY OUT OF THE USE OF THIS SOFTWARE, EVEN IF ADVISED OF THE
 * POSSIBILITY OF SUCH DAMAGE.
 */

#include "esp_log.h"
#include "led_strip.h"
#include "weather_driver.h"
#include "driver/gpio.h"
#include "freertos/FreeRTOS.h"
#include "freertos/task.h"
#include "freertos/queue.h"


static led_strip_handle_t s_led_strip;
static uint8_t s_red = 255, s_green = 255, s_blue = 255;
static bool s_led_power_state = false;  // Track LED power state

void light_driver_set_power(bool power)
{
    s_led_power_state = power;  // Update state tracker
    ESP_ERROR_CHECK(led_strip_set_pixel(s_led_strip, 0, s_red * power, s_green * power, s_blue * power));
    ESP_ERROR_CHECK(led_strip_refresh(s_led_strip));
}

bool light_driver_get_power(void)
{
    return s_led_power_state;
}

void light_driver_set_gpio_power(bool power)
{
    gpio_set_level(CONFIG_EXAMPLE_GPIO_LED, power ? 1 : 0);
}

void light_driver_init(bool power)
{
    // Initialize LED strip
    led_strip_config_t led_strip_conf = {
        .max_leds = CONFIG_EXAMPLE_STRIP_LED_NUMBER,
        .strip_gpio_num = CONFIG_EXAMPLE_STRIP_LED_GPIO,
    };
    led_strip_rmt_config_t rmt_conf = {
        .resolution_hz = 10 * 1000 * 1000, // 10MHz
    };
    ESP_ERROR_CHECK(led_strip_new_rmt_device(&led_strip_conf, &rmt_conf, &s_led_strip));
    light_driver_set_power(power);
    
    // Initialize GPIO LED
    gpio_config_t io_conf = {
        .intr_type = GPIO_INTR_DISABLE,
        .mode = GPIO_MODE_OUTPUT,
        .pin_bit_mask = (1ULL << CONFIG_EXAMPLE_GPIO_LED),
        .pull_down_en = 0,
        .pull_up_en = 0,
    };
    gpio_config(&io_conf);
    light_driver_set_gpio_power(false);
    
    // Initialize Button GPIO (input with pull-down - external pull-down resistor)
    // Reset the GPIO to make sure it's not configured for other functions
    gpio_reset_pin(CONFIG_EXAMPLE_BUTTON_GPIO);
    
    gpio_config_t button_conf = {
        .intr_type = GPIO_INTR_DISABLE,
        .mode = GPIO_MODE_INPUT,
        .pin_bit_mask = (1ULL << CONFIG_EXAMPLE_BUTTON_GPIO),
        .pull_down_en = 0,  // External pull-down resistor
        .pull_up_en = 0,
    };
    gpio_config(&button_conf);
}



/* Builtin button interrupt-based implementation (based on ESP-IDF switch example) */
static QueueHandle_t builtin_button_evt_queue = NULL;
static builtin_button_callback_t builtin_button_callback = NULL;
static const char *BUILTIN_BUTTON_TAG = "BUILTIN_BUTTON";

static void IRAM_ATTR builtin_button_isr_handler(void *arg)
{
    uint32_t gpio_num = CONFIG_EXAMPLE_BUILTIN_BUTTON_GPIO;
    xQueueSendFromISR(builtin_button_evt_queue, &gpio_num, NULL);
}

static void builtin_button_task(void *arg)
{
    uint32_t io_num;
    builtin_button_state_t button_state = BUILTIN_BUTTON_IDLE;
    bool evt_flag = false;
    TickType_t press_start_time = 0;
    bool long_press_reported = false;
    const TickType_t LONG_PRESS_DURATION = pdMS_TO_TICKS(5000); // 5 seconds for factory reset
    const TickType_t MAX_BUTTON_TASK_DURATION = pdMS_TO_TICKS(10000); // 10 seconds max task duration
    TickType_t task_start_time = 0;

    for (;;) {
        /* Wait for button interrupt */
        if (xQueueReceive(builtin_button_evt_queue, &io_num, portMAX_DELAY)) {
            /* Disable interrupts during debouncing */
            gpio_intr_disable(CONFIG_EXAMPLE_BUILTIN_BUTTON_GPIO);
            evt_flag = true;
            task_start_time = xTaskGetTickCount();  // Track when we started processing
        }
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

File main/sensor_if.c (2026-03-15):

#include "sensor_if.h"
#include "bme280_app.h" // existing BME280 app API
#include "aht20.h"
#include "bmp280.h"
#include "sht41.h"
#include "esp_log.h"
#include "i2c_bus.h"
#include <stdio.h>

static const char *TAG = "SENSOR_IF";
static sensor_type_t detected = SENSOR_TYPE_NONE;

// Default pressure value when no pressure sensor is available (SHT41 case)
#define DEFAULT_PRESSURE_HPA 1000.0f

esp_err_t sensor_init(i2c_bus_handle_t i2c_bus)
{
    esp_err_t ret = ESP_ERR_NOT_FOUND;

    if (i2c_bus != NULL) {
        // Diagnostic scan: list all devices on the bus to help debug NACKs
        uint8_t found[32];
        int n = i2c_bus_scan(i2c_bus, found, sizeof(found));
        if (n == 0) {
            ESP_LOGW(TAG, "I2C scan: no devices found on bus");
        } else {
            char buf[128];
            int off = 0;
            off += snprintf(buf + off, sizeof(buf) - off, "I2C scan: %d device(s):", n);
            for (int i = 0; i < n; ++i) off += snprintf(buf + off, sizeof(buf) - off, " 0x%02x", found[i]);
            ESP_LOGI(TAG, "%s", buf);
        }
    } else {
        ESP_LOGW(TAG, "sensor_init: i2c_bus handle is NULL");
    }

    // Try BME280 first (existing single-chip sensor)
    ESP_LOGI(TAG, "Probing for BME280...");
    ret = bme280_app_init(i2c_bus);
    if (ret == ESP_OK) {
        // Check if it's actually a BMP280 (no humidity) - if so, look for humidity sensor combo
        if (bme280_app_is_bmp280()) {
            ESP_LOGI(TAG, "BMP280 detected (no humidity), searching for separate humidity sensor...");
            
            // Initialize standalone BMP280 module for combo sensor support
            esp_err_t bmp_ret = bmp280_init(i2c_bus);
            if (bmp_ret != ESP_OK) {
                ESP_LOGW(TAG, "Failed to initialize standalone BMP280 module: %s", esp_err_to_name(bmp_ret));
            }
            
            // Try to find SHT41 for humidity
            esp_err_t sht_ret = sht41_init(i2c_bus);
            if (sht_ret == ESP_OK) {
                detected = SENSOR_TYPE_SHT41_BMP280;
                ESP_LOGI(TAG, "Detected sensor combo: SHT41 + BMP280 (temp/RH from SHT41, pressure from BMP280)");
                return ESP_OK;
            }
            ESP_LOGW(TAG, "No humidity sensor found, using BMP280 alone (humidity unavailable)");
        }
        detected = SENSOR_TYPE_BME280;
        ESP_LOGI(TAG, "Detected sensor: BME280");
        return ESP_OK;
    }

    // Try SHT41 + BMP280 combo (temp+humidity from SHT41, pressure from BMP280)
    ESP_LOGI(TAG, "BME280 not found, probing for SHT41 + BMP280 combo...");
    esp_err_t sht_ret = sht41_init(i2c_bus);
    esp_err_t bmp_ret = bmp280_init(i2c_bus);
    if (sht_ret == ESP_OK && bmp_ret == ESP_OK) {
        detected = SENSOR_TYPE_SHT41_BMP280;
        ESP_LOGI(TAG, "Detected sensor combo: SHT41 + BMP280 (temp/RH from SHT41, pressure from BMP280)");
        return ESP_OK;
    }

    // Try SHT41 alone (temp + humidity only, no pressure)
    if (sht_ret == ESP_OK) {
        ESP_LOGI(TAG, "Detected sensor: SHT41 only (pressure will default to %.1f hPa)", DEFAULT_PRESSURE_HPA);
        detected = SENSOR_TYPE_SHT41;
        return ESP_OK;
    }

    // Try AHT20 + BMP280 combo
    ESP_LOGI(TAG, "SHT41 not found, probing for AHT20 + BMP280 combo...");
    ret = aht20_init(i2c_bus);
    if (ret != ESP_OK) {
        ESP_LOGW(TAG, "AHT20 not present or init failed");
        return ESP_ERR_NOT_FOUND;
    }
    ret = bmp280_init(i2c_bus);
    if (ret != ESP_OK) {
        ESP_LOGW(TAG, "BMP280 not present or init failed");
        return ESP_ERR_NOT_FOUND;
    }

    detected = SENSOR_TYPE_AHT20_BMP280;
    ESP_LOGI(TAG, "Detected sensor combo: AHT20 + BMP280");
    return ESP_OK;
}

sensor_type_t sensor_get_type(void)
{
    return detected;
}

esp_err_t sensor_wake_and_measure(void)
{
    if (detected == SENSOR_TYPE_BME280) {
        return bme280_app_wake_and_measure();
    } else if (detected == SENSOR_TYPE_SHT41) {
        return sht41_trigger_measurement();
    } else if (detected == SENSOR_TYPE_SHT41_BMP280) {
        esp_err_t r1 = sht41_trigger_measurement();
        esp_err_t r2 = bmp280_trigger_measurement();
        if (r2 != ESP_OK) ESP_LOGW(TAG, "BMP280 trigger failed (%s) - pressure will be stale", esp_err_to_name(r2));
        // Return OK if at least one succeeds (allows partial functionality)
        return (r1 == ESP_OK || r2 == ESP_OK) ? ESP_OK : ESP_FAIL;
    } else if (detected == SENSOR_TYPE_AHT20_BMP280) {
        esp_err_t r1 = aht20_trigger_measurement();
        esp_err_t r2 = bmp280_trigger_measurement();
        if (r2 != ESP_OK) ESP_LOGW(TAG, "BMP280 trigger failed (%s) - pressure will be stale", esp_err_to_name(r2));
        // Return OK if at least one succeeds (allows partial functionality)
        return (r1 == ESP_OK || r2 == ESP_OK) ? ESP_OK : ESP_FAIL;
    }
    return ESP_ERR_NOT_FOUND;
}

esp_err_t sensor_read_temperature(float *out_c)
{
    if (!out_c) return ESP_ERR_INVALID_ARG;
    if (detected == SENSOR_TYPE_BME280) {
        return bme280_app_read_temperature(out_c);
    } else if (detected == SENSOR_TYPE_SHT41) {
        return sht41_read_temperature(out_c);
    } else if (detected == SENSOR_TYPE_SHT41_BMP280) {
        // Read temperature from SHT41 (preferred for accuracy)
        return sht41_read_temperature(out_c);
    } else if (detected == SENSOR_TYPE_AHT20_BMP280) {
        // Read temperature from AHT20 (preferred) or BMP280 as fallback
        esp_err_t ret = aht20_read_temperature(out_c);
        if (ret == ESP_OK) return ESP_OK;
        return bmp280_read_temperature(out_c);
    }
    return ESP_ERR_NOT_FOUND;
}

esp_err_t sensor_read_humidity(float *out_percent)
{
    if (!out_percent) return ESP_ERR_INVALID_ARG;
    if (detected == SENSOR_TYPE_BME280) {
        if (bme280_app_is_bmp280()) return ESP_ERR_NOT_SUPPORTED;
        return bme280_app_read_humidity(out_percent);
    } else if (detected == SENSOR_TYPE_SHT41) {
        return sht41_read_humidity(out_percent);
    } else if (detected == SENSOR_TYPE_SHT41_BMP280) {
        return sht41_read_humidity(out_percent);
    } else if (detected == SENSOR_TYPE_AHT20_BMP280) {
        return aht20_read_humidity(out_percent);
    }
    return ESP_ERR_NOT_FOUND;
}
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

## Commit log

2025-10-16 Project creation
    [partitions.csv]
2025-11-06 Add battery monitoring functionality: implement battery voltage and percentage reporting, and refine ADC calibration for ESP32-H2
2025-11-06 Update project version to 1.1.10, enhance OTA support, and optimize battery reading logic
2025-11-06 Enhance LED debug control logging for Zigbee messages
2025-11-10 Refactor code structure for improved readability and maintainability + Add KiCad PCB project
    [caelum.kicad_pcb, caelum.kicad_sch]
2025-11-11 Update sdkconfig for light sleep features
    [caelum.kicad_sch]
2025-11-11 Refactor LED control logic for improved power management during network operations. Deinitialize LED after successful join to save power, and update LED behavior for connection states. Remove unused 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
2025-11-12 Refactor rain gauge and sleep configuration handling. Remove sleep duration reporting and configuration endpoint to streamline Zigbee operations. Update reporting intervals for rain gauge and battery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
2025-11-12 Refactor LED control logic for improved power management during network operations. Deinitialize LED after successful join to save power and update LED behavior for connection states.
2025-11-12 Update project version to 1.5 and reset build number to 0. Modify rain gauge task to save rainfall data on every pulse to prevent data loss during unexpected reboots.
    [esp_zb_weather.c]
2025-11-13 Add AHT20 and BMP280 sensor support
    - Implemented AHT20 sensor driver with initialization, measurement triggering, and data reading functions.
    - Implemented BMP280 sensor driver with initialization, measurement triggering, and data reading functions.
    - Updated sensor interface to support detection and interaction with AHT20 and BMP280 sensors.
    - Enhanced I2C bus scanning for better device detection and debugging.
    - Updated sdkconfig to enable necessary configurations for new sensors.
2025-11-15 Update project version to 1.7 and reset build number to 0. Add timeout handling in button task to prevent infinite loops.
    [weather_driver.c]
2025-12-04 feat: Enhance Caelum Weather Station functionality and configuration
    - Updated PCB configuration to set active layer to 0 and adjusted column widths for better layout.
    - Expanded device endpoints in the weather station to include additional sensors (pulse counter and temperature).
    - Implemented sleep prevention during initial network configuration to ensure proper reporting setup.
    - Added logic to load and save pulse counter data to RTC and NVS for persistence across power cycles.
    - Improved DS18B20 sensor initialization with retry logic for better reliability.
    - Enhanced logging for various operations to provide clearer insights during execution.
    - Updated SDK configuration for flash settin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
    [caelum.kicad_pcb]
2025-12-18 Add files for PCB and schematic in caelum_v2
    [caelum_v2.kicad_pcb, caelum_v2.kicad_sch]
2025-12-18 Move PCB V2 to new project
    [caelum_v2-B_Cu.gbl, caelum_v2-B_Mask.gbs, caelum_v2-B_Paste.gbp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]
2025-12-26 Update BMP280 driver: add raw ADC reading functions and improve pressure reading logic
2025-12-28 Update build number to 50 and improve BMP280 pressure conversion handling with busy-wait
2025-12-29 Add logging to flash to debug crashes
    [partitions.csv]
2026-03-07 Restore exponential backoff reconnect logic from build branch
    On LEAVE signal: schedule automatic rejoin in 5s instead of stopping.
    After 20 fast retries (1s each): switch to exponential backoff starting
    at 30s, doubling up to 10 minutes cap, instead of giving up entirely.
    Backoff and retry counters reset on successful join.
    [esp_zb_weather.c]
2026-03-07 Fix missing backoff and deinit_cb declarations in esp_zb_weather.c
    Add missing symbols that caused build errors:
    - debug_led_deinit_cb: typed wrapper for scheduler alarm (avoids UB cast)
    - backoff_attempt variable and BACKOFF_* defines
    - get_backoff_delay_ms() function
    [esp_zb_weather.c]
2026-03-07 Fix bugs found in code review
    - esp_zb_weather: replace remaining UB cast of debug_led_deinit with
    debug_led_deinit_cb wrapper on successful join path
    - esp_zb_weather: remove duplicate load_rainfall_data call in app_main
    whose result was never used (real load happens earlier at cluster init)
    - persistent_log: reduce MAX_LOG_ENTRIES from 1000 to 50 to match design
    intent and prevent NVS exhaustion (~118KB → ~6KB)
    - persistent_log: dump_and_clear now actually clears after dumping
    - sleep_manager: remove meaningless >= 0.0f RTC validity guards (float
    is always >= 0.0f, making the check always true)
    - sensor_if: log warning when BMP280 trigger fails in combo mode so
    stale pressure r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
    [esp_zb_weather.c, sensor_if.c, sleep_manager.c]
2026-03-14 Refactor esp_zb_weather.c to remove persistent logging and optimize power management settings
2026-03-14 Improve ESP32 magic byte search logic in Zigbee OTA handler to account for header offset
2026-03-14 Enhance sensor handling and logging: update humidity endpoint, add initial sensor read trigger, and handle NaN/Inf values in RTC data
2026-04-18 Add PM lock for initial configuration to prevent sleep during network join
    [esp_zb_weather.c]
2026-04-19 Refactor Zigbee reporting configuration to eliminate lock acquisition
    - Removed unnecessary lock acquisition for rain gauge and pulse counter reporting configuration, as these are now called from the Zigbee task context.
    - Updated the battery read and report function to include lock acquisition for attribute updates.
    - Adjusted the handling of attribute updates for DS18B20, rain gauge, and pulse counter to ensure proper locking mechanisms are in place.
    - Modified sdkconfig to change console settings and improve UART configurations.
    - Added boot log to capture detailed startup information and error handling.
    [esp_zb_weather.c]
2026-04-19 Add critical section protection for DS18B20 1-Wire communication to prevent interrupt preemption
    [esp_zb_weather.c]
